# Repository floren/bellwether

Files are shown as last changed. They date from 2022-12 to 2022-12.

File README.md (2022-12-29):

# The Bellwether Mouse

This repo should contain everything you need to make a [Bellwether mouse](https://jfloren.net/bellwether.html).

Note that I've made several of these myself, but it's possible that I've forgotten a step or component somewhere.

I'm willing to answer questions to the best of my ability. I'll also consider assembling some portions of the mouse and mailing it out; send me an email if you want this.

The 3d models and the circuit are CC BY-NC-SA licensed. I believe this means that "group buys" (where 1 person coordinates ordering a bunch of PCBs and parts) are ok under this model.

## 3D-printed case

Inside the case/ subdirectory you'll find two FreeCAD files, "base" (the bottom part of the mouse) and "body" (the curved top which fits in your hand).

These should be printed in PLA. I've had good luck with my Prusa Mini. I strongly suggest using a raft when printing the body, and *not* using a raft for the base.

Check out the releases for pre-built STL files.

## PCB

The board was designed using KiCAD. If you use OSH Park, you should be able to just upload board/depraz_board.kicad_pcb directly on their site. For other PCB services, you may need to open KiCAD and export Gerber files etc.

## Circuit & BOM

You can check out the schematic in schematic.pdf

bom.csv is a circuit bill of materials. Most stuff should be available from parts companies in the US, but for the PMW3389 sensor you'll probably need to go to AliExpress (e.g. https://www.aliexpress.us/item/2251832705021246.html)

You'll also need 3 momentary pushbutton switches such as https://www.digikey.com/en/products/detail/5501M1BLKX/EG1701-ND/101654

Although you don't have to, I recommend using a DIP socket for the microcontroller in case you toast the microcontroller.

## Assembly

### Circuit assembly

In general it's all pretty straightforward but I strongly recommend installing the SMD level shifters first, all the rest of the components next, and then do the mouse sensor *last*.

### Doing the switches

I recommend gluing down the switches first. Gently pry off the button from each switch and set it aside. Then put a small dab of Gorilla Glue in the slot on the base, press the switch onto it, and make sure it's aligned straight. Use a clamp to hold the switch in place while the glue dries (I used something like https://www.amazon.com/Professional-Plastic-Backdrop-Photography-Improvement/dp/B08RXW32H4/). Once the glue is dry, make sure the switch is firmly seated and use an exacto knife to trim away any glue which oozed out, then press the button back onto the switch face.

Solder two wires onto each switch, on the normally-open pins. The wires should have Dupont pin connectors on the ends; I just took some jumper wires I had lying around (with a connector on each end) and cut them in half. See http://jfloren.net/content/bellwether/base2.jpg

### Physical assembly

You'll need the following parts to assemble the case:

* 8x M2x0.4mm heatserts: https://www.mcmaster.com/94459A120/
* 4x M2x0.4mm flathead screws (for the bottom): https://www.mcmaster.com/91294A003/
* 4x M2x0.4mm button head screws (to hold the board down): https://www.mcmaster.com/92095A451/

Additional stuff you'll want:

* A USB cable. Should be USB-A on one end, and a female pin header connector at the other. You can start with https://www.digikey.com/en/products/detail/assmann-wsw-components/A-USB20AM-OE-200BK28/10408422 and use https://www.amazon.com/Taiss-Ratcheting-Connector-Crimping-Terminal/dp/B0B11RLGDZ to crimp on a 4-pin header to the other end. You may be able to find these pre-made, e.g. https://www.amazon.com/dp/B07ZPT2NMT
* Friction tape (https://www.amazon.com/gp/product/B0000CBIAT) to wrap around the USB cable where it leaves the mouse. This appears to be what my original Depraz mouse used.
* Teflon tape to make skates for the bottom. I used https://www.amazon.com/gp/product/B01LZ44P6M and punched out pieces using https://www.amazon.com/gp/product/B00006IBK9

Use your soldering iron to install the heatserts flush in the corresponding holes of the case.

Position the lens on the bottom of the mouse sensor, then set the PCB on the 3d printed base. Use the button-head screws to hold down the PCB; don't overtighten!

Plug in the switches. Note that the headers on the board are labeled R, M, and L for right, middle, and left.

Plug the USB cable into the 4-pin USB header. Lay it across the board to where the cable hole in the case will go; mark this point and put a layer or two of friction tape on the cable there.

Gently slide the top of the case over the switches; there's a "right way" to do it, which takes a bit of gentle experimentation to find. Once you get the two pieces together, use flathead screws to hold them together.

Punch out four pieces of Teflon tape and stick them to the bottom for skates.

### Flashing the firmware

The firmware organization sucks, but I am not good enough at PIC programming to properly clean it up. PRs welcome.

Plug your PIC programmer into the PROGRAM header on the board.

Open MPLAB X IDE and load firmware/depraz/apps/usb/device/hid_mouse/firmware/low_pin_count_usb_development_kit_pic16f1459.x

I found that it worked when I set up the PICkit3 to provide power at 3.5V. Your other option is to plug in the USB cable before programming to power the device externally.

### Adding heft

You'll probably find that the mouse by itself is way too light. I hot-glued a bunch of lead fishing weights to the inside and it was much more pleasant.

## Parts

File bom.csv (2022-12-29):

Reference | Quantity | Value | Footprint | Datasheet
C1 | 1 | 0.1uF | Capacitor_THT:C_Disc_D8.0mm_W2.5mm_P5.00mm | ~
C2 | 1 | 4.7uF | Capacitor_THT:C_Disc_D4.7mm_W2.5mm_P5.00mm | ~
J1 | 1 | Switches | Connector_PinHeader_2.54mm:PinHeader_1x06_P2.54mm_Vertical | ~
J2 | 1 | PIC Programmer | Connector_PinHeader_2.54mm:PinHeader_1x05_P2.54mm_Vertical | ~
J3 | 1 | USB | Connector_PinHeader_2.54mm:PinHeader_1x04_P2.54mm_Vertical | ~
R1 R2 R3 | 3 | 1M | Resistor_THT:R_Axial_DIN0207_L6.3mm_D2.5mm_P5.08mm_Vertical | ~
R4 | 1 | 13 | Resistor_THT:R_Axial_DIN0207_L6.3mm_D2.5mm_P5.08mm_Vertical | ~
U1 | 1 | PIC16F1454-IP | Package_DIP:DIP-14_W7.62mm | http://ww1.microchip.com/downloads/en/DeviceDoc/41639A.pdf
U2 U3 | 2 | TXB0104D | Package_SO:SOIC-14_3.9x8.7mm_P1.27mm | http://www.ti.com/lit/ds/symlink/txb0104.pdf
U4 | 1 | S-817B20AY-B2-U | Package_TO_SOT_THT:TO-92L_Inline | https://www.ablic.com/en/doc/datasheet/voltage_regulator/S817_E.pdf
U5 | 1 | PMW3389DM | depraz_board:pmw3389

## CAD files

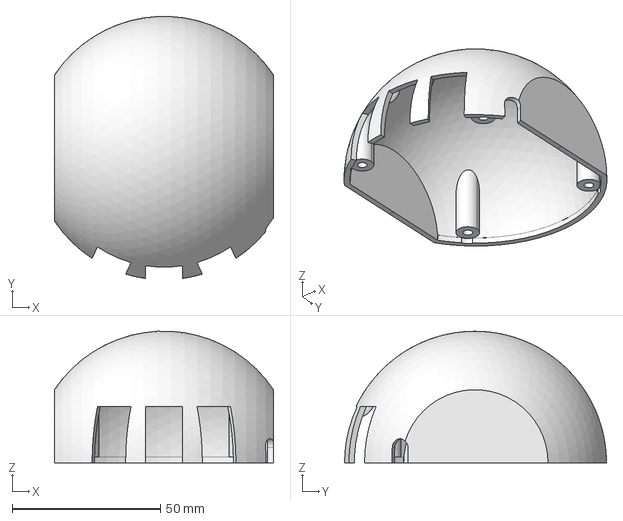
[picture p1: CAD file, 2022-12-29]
case/body.FCStd
74.1 x 88.5 x 44.4 mm

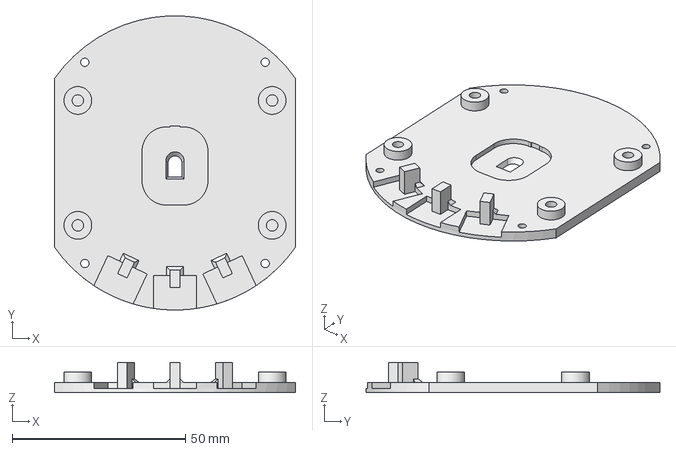
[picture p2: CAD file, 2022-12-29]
case/base.FCStd
69.5 x 84.7 x 8.75 mm

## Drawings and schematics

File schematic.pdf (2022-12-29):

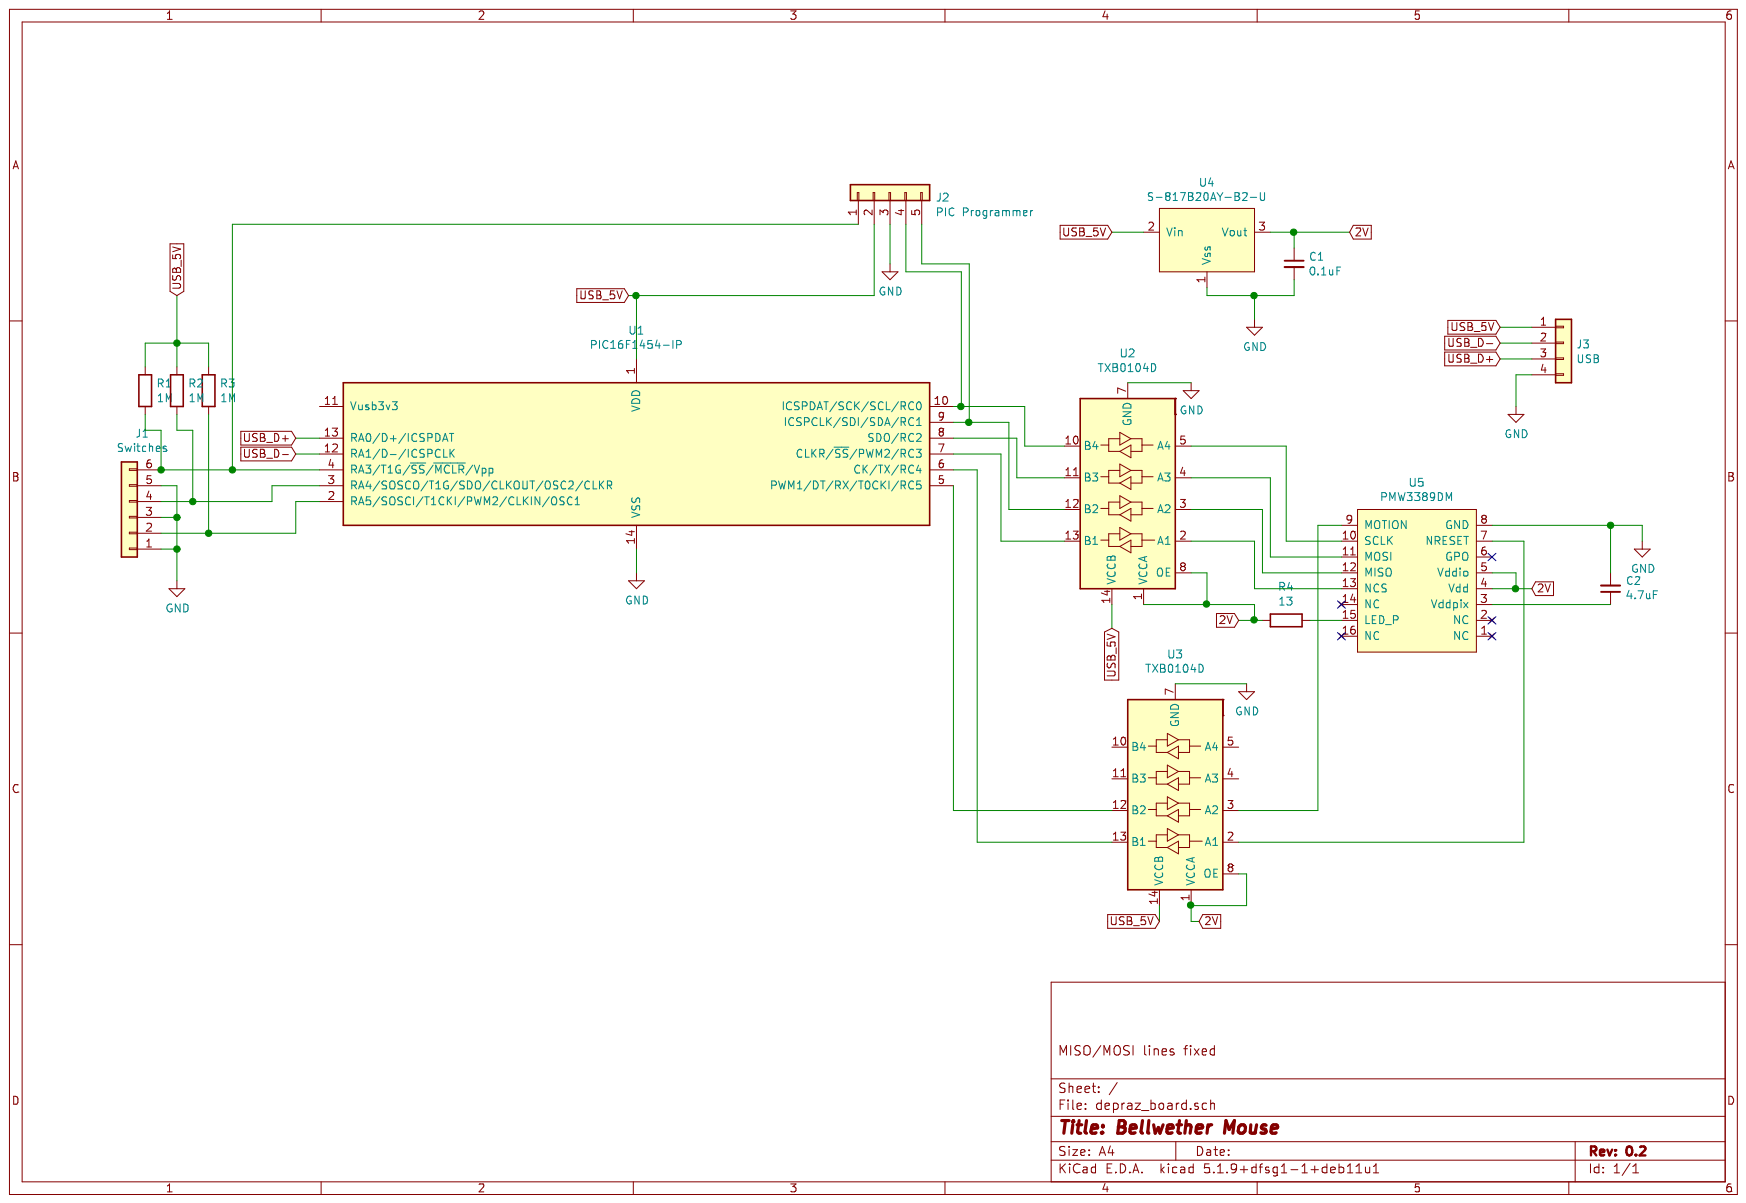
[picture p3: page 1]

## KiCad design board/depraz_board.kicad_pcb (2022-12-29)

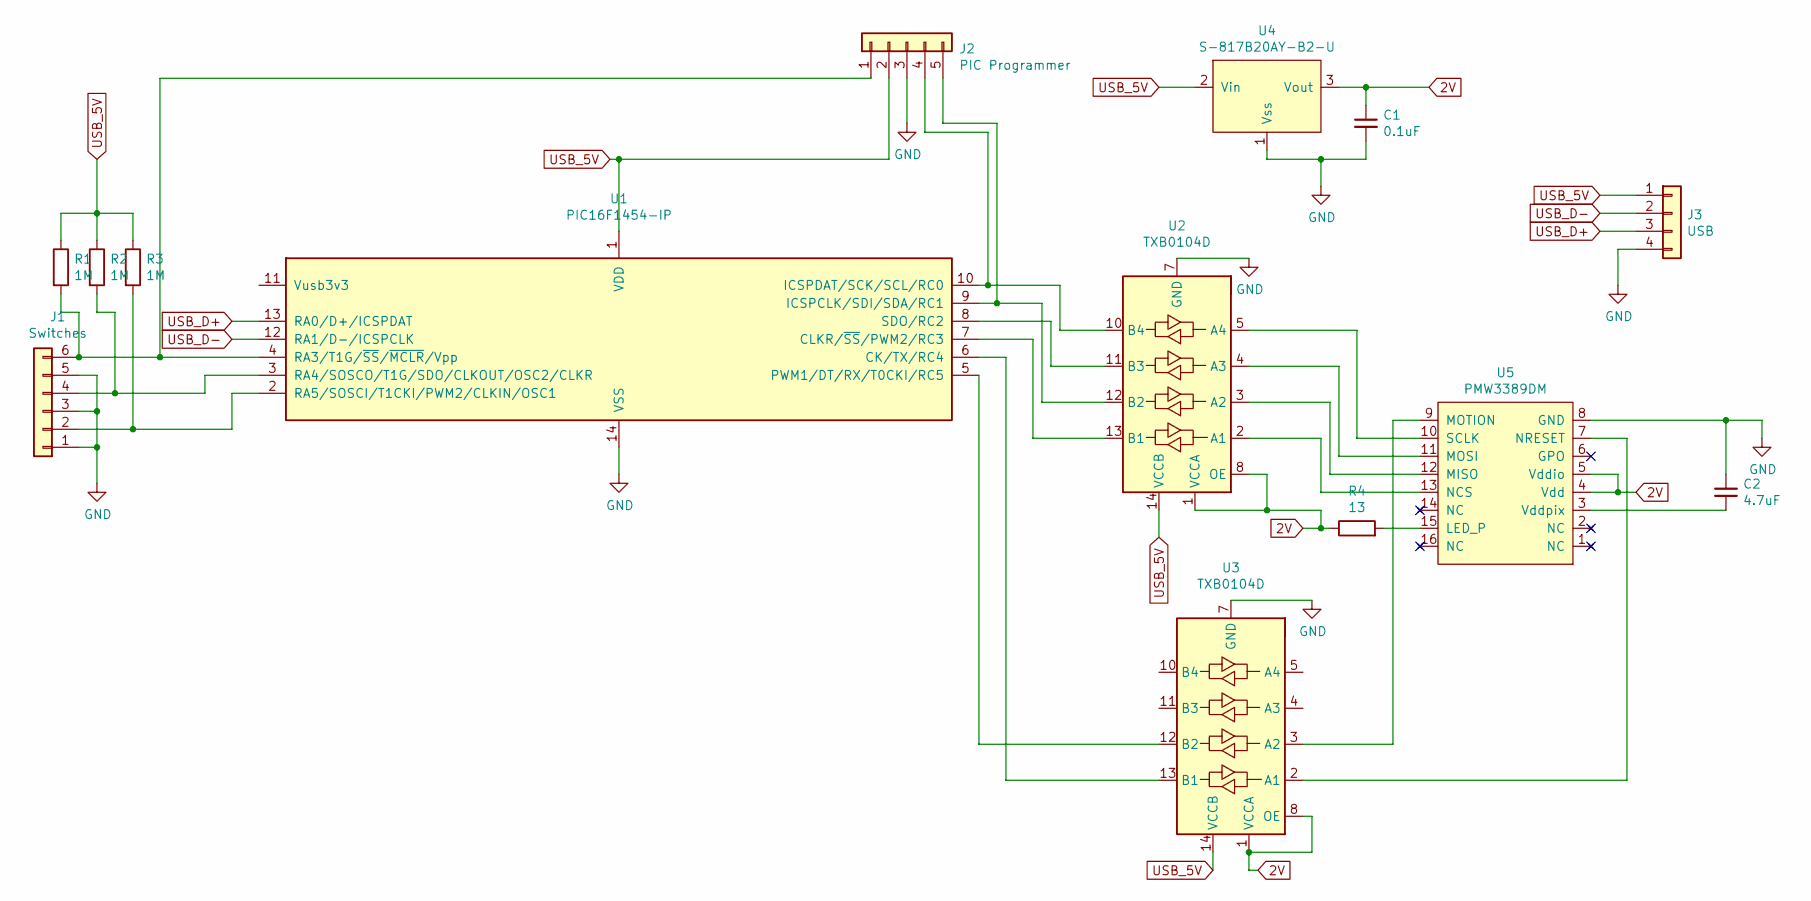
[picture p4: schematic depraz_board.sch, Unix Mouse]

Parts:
C1: 0.1uF; C_Disc_D8.0mm_W2.5mm_P5.00mm
C2: 4.7uF; C_Disc_D4.7mm_W2.5mm_P5.00mm
J1: Switches; PinHeader_1x06_P2.54mm_Vertical
J2: PIC Programmer; PinHeader_1x05_P2.54mm_Vertical
J3: USB; PinHeader_1x04_P2.54mm_Vertical
R1, R2, R3: 1M; R_Axial_DIN0207_L6.3mm_D2.5mm_P5.08mm_Vertical
R4: 13; R_Axial_DIN0207_L6.3mm_D2.5mm_P5.08mm_Vertical
U1: PIC16F1454-IP; DIP-14_W7.62mm
U2, U3: TXB0104D; SOIC-14_3.9x8.7mm_P1.27mm
U4: S-817B20AY-B2-U; TO-92L_Inline
U5: PMW3389DM; pmw3389

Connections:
2V: C1.1, R4.1, U2.1 (VCCA), U2.8 (OE), U3.1 (VCCA), U3.8 (OE), U4.3 (Vout), U5.4 (Vdd), U5.5 (Vddio)
GND: C1.2, C2.2, J1.1, J1.3, J1.5, J2.3, J3.4, U1.14 (VSS), U2.7 (GND), U3.7 (GND), U4.1 (Vss), U5.8 (GND)
unnamed: C2.1, U5.3 (Vddpix)
unnamed: J1.2, R3.2, U1.2 (RA5/SOSCI/T1CKI/PWM2/CLKIN/OSC1)
unnamed: J1.4, R2.2, U1.3 (RA4/SOSCO/T1G/SDO/CLKOUT/OSC2/CLKR)
unnamed: J1.6, J2.1, R1.2, U1.4 (RA3/T1G/~SS~/~MCLR~/Vpp)
unnamed: J2.4, U1.10 (ICSPDAT/SCK/SCL/RC0), U2.10 (B4)
unnamed: J2.5, U1.9 (ICSPCLK/SDI/SDA/RC1), U2.12 (B2)
unnamed: R4.2, U5.15 (LED_P)
unnamed: U1.5 (PWM1/DT/RX/T0CKI/RC5), U3.12 (B2)
unnamed: U1.6 (CK/TX/RC4), U3.13 (B1)
unnamed: U1.7 (CLKR/~SS~/PWM2/RC3), U2.13 (B1)
unnamed: U1.8 (SDO/RC2), U2.11 (B3)
unnamed: U2.2 (A1), U5.13 (NCS)
unnamed: U2.3 (A2), U5.12 (MISO)
unnamed: U2.4 (A3), U5.11 (MOSI)
unnamed: U2.5 (A4), U5.10 (SCLK)
unnamed: U3.2 (A1), U5.7 (NRESET)
unnamed: U3.3 (A2), U5.9 (MOTION)
USB_5V: J2.2, J3.1, R1.1, R2.1, R3.1, U1.1 (VDD), U2.14 (VCCB), U3.14 (VCCB), U4.2 (Vin)
USB_D+: J3.3, U1.13 (RA0/D+/ICSPDAT)
USB_D-: J3.2, U1.12 (RA1/D-/ICSPCLK)

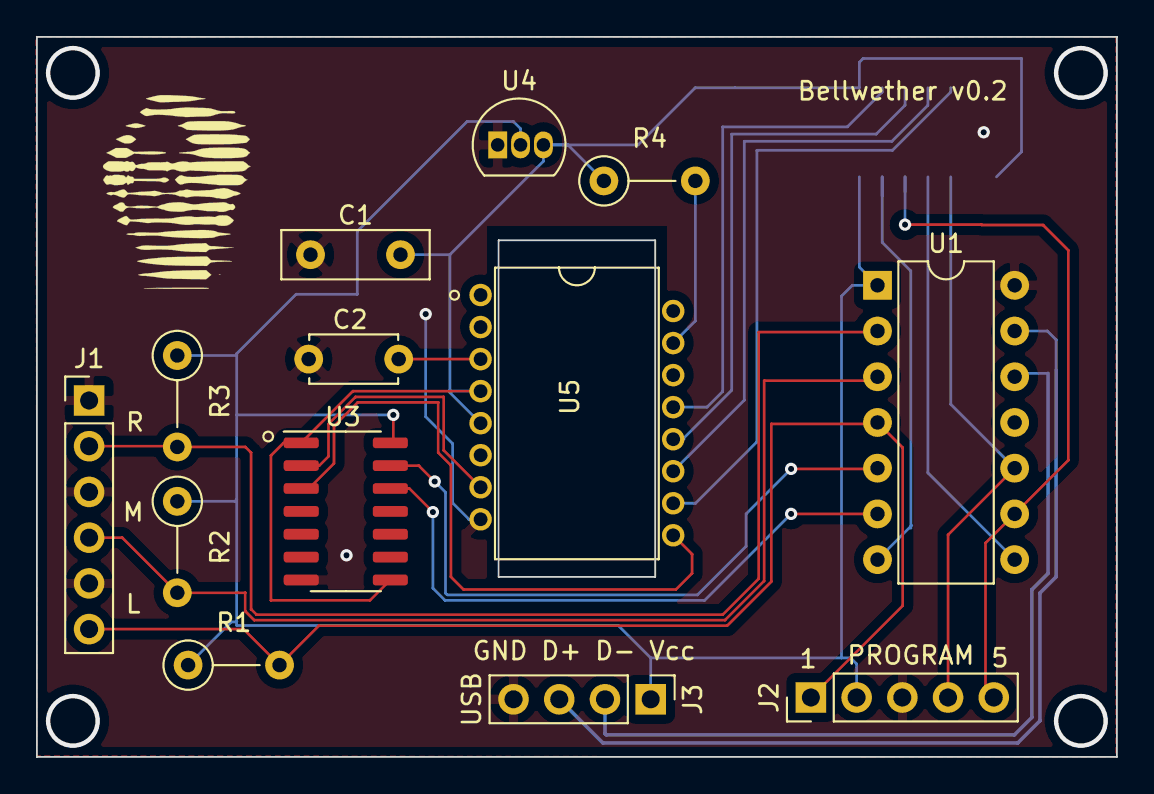
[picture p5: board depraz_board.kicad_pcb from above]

Board: 2 copper layers, 60.0 x 40.0 mm, 14 parts (1 on the bottom side), 22 nets.

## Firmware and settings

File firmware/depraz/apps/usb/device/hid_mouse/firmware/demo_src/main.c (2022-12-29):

/*******************************************************************************
Copyright 2016 Microchip Technology Inc. (www.microchip.com)

Licensed under the Apache License, Version 2.0 (the "License");
you may not use this file except in compliance with the License.
You may obtain a copy of the License at

    http://www.apache.org/licenses/LICENSE-2.0

Unless required by applicable law or agreed to in writing, software
distributed under the License is distributed on an "AS IS" BASIS,
WITHOUT WARRANTIES OR CONDITIONS OF ANY KIND, either express or implied.
See the License for the specific language governing permissions and
limitations under the License.

To request to license the code under the MLA license (www.microchip.com/mla_license), 
please contact mla_licensing@microchip.com
*******************************************************************************/

/** INCLUDES *******************************************************/
#include "system.h"

#include "usb_device.h"
#include "usb_device_hid.h"
#include "usb_device_cdc.h"

#include "app_device_mouse.h"
#include "app_led_usb_status.h"
#include "pmw3389.h"


void spi_begin() {
    NCS = 0;
}

void spi_end() {
    NCS = 1;
}

unsigned char spi_read_reg(unsigned char addr) {
    unsigned char data;
    unsigned char x;
    
    x = SSPBUF;
    // Send the address we want to read
    spi_begin();
    // write the address with MSB low (read)
    SSPBUF = addr & 0x7f;
    while (!BF);
    x = SSPBUF; // read whatever they sent, it doesn't matter
    __delay_us(35); // tsrad
    
    // Now get the result they sent
    SSPBUF = 0x1; // send some nonsense, so we can receive the actual value
    while (!BF);
    spi_end();
    __delay_us(20);
    data = SSPBUF; // read the data

    return data;
}

void spi_write_reg(unsigned char addr, unsigned char value) {
    unsigned char x;
    spi_begin();
    // write the address with MSB high
    SSPBUF = addr | 0x80;
    while (BF == 0);
    x = SSPBUF; // read whatever nonsense they sent
    __delay_us(1);
    // Now send the data
    SSPBUF = value;
    while (BF == 0);
    x = SSPBUF; // read whatever we received, we don't care
    __delay_us(20);
    spi_end();
    __delay_us(100);
}

void get_burst(unsigned char* buff) {
    int i;
    
    spi_begin();
    // write somethign to motion burst buffer
    spi_write_reg(Motion_Burst, 0x1);
    
    // Read from the motion burst buffer
    spi_read_reg(Motion_Burst);
    __delay_us(35);
    
    // Now read 12 bytes
    for (i = 0; i < 12; i++) {
        SSPBUF = Motion_Burst;
        while (BF == 0);
        buff[i] = SSPBUF;
    }
    spi_end();
}

/********************************************************************
 * Function:        void main(void)
 *
 * PreCondition:    None
 *
 * Input:           None
 *
 * Output:          None
 *
 * Side Effects:    None
 *
 * Overview:        Main program entry point.
 *
 * Note:            None
 *******************************************************************/
MAIN_RETURN main(void)
{
    SYSTEM_Initialize(SYSTEM_STATE_USB_START);

    USBDeviceInit();
    USBDeviceAttach();

    ANSELA = 0x0;
    ANSELC = 0x0;
    TRISA=0b00111000;
    TRISC=0b00100010;
    
    // Reset SPI on the PIC
    SSPCON1 = 0;
    SSPCON2 = 0;
    SSPCON1bits.SSPM = 0x1;
    SSPCON1bits.CKP = 1; // clock polarity
    SSPSTATbits.CKE = 0; // clock edge select
    SSPCON1bits.SSPEN = 1; // enable SPI

    __delay_ms(1);
    
    // reset device's SPI port
    spi_begin();
    __delay_us(50);
    spi_end();
    __delay_us(50);

    
    // Reset the sensor
    NRESET = 0;
    __delay_ms(50);
    NRESET = 1;
    __delay_ms(50);
    
    unsigned char x;
    x = spi_read_reg(Product_ID);
    x = spi_read_reg(Product_ID);
    x = spi_read_reg(Motion);
    x = spi_read_reg(Delta_X_L);
    x = spi_read_reg(Delta_X_H);
    x = spi_read_reg(Delta_Y_L);
    x = spi_read_reg(Delta_Y_H);
    __delay_ms(1);
    
    // Set the CPI
#define CPI 800
    uint16_t cpival;
    cpival = CPI / 50;
    spi_write_reg(Resolution_L, (cpival & 0xFF));
    spi_write_reg(Resolution_H, (cpival >> 8) & 0xFF);
    
    //write_firmware();
    
    // write to Motion register to kick things off
    spi_write_reg(Motion, 0x1);
    
    int8_t motion, xl, xh, yl, yh;
    int16_t X, Y;
    int8_t left, right, mid;
    while(1)
    {
        //spi_read_reg(Product_ID);
        motion = 0x00;
        motion = spi_read_reg(Motion);
        dx = dy = 0;
        if (motion & 0x80) {
            xl = spi_read_reg(Delta_X_L);
            xh = spi_read_reg(Delta_X_H);
            yl = spi_read_reg(Delta_Y_L);
            yh = spi_read_reg(Delta_Y_H);
            X = (xh << 8) | xl;
            Y = (yh << 8) | yl;
            dx = -X;
            dy = -Y;
        }
        
        // Watchdog... if we actually read from the register,
        // this bit will be set
        if (motion & 0x20) {
            CLRWDT();
        }
        
        // Mouse button debouncing
        left = BUTTON_LEFT;
        if (!left) {
            // button is currently pressed
            leftCounter = (leftCounter<=THRESH)?leftCounter+1:leftCounter;
        } else {
            leftCounter = (leftCounter>0)?leftCounter-1:0;
        }
        
        right = BUTTON_RIGHT;
        if (!right) {
            // button is currently pressed
            rightCounter = (rightCounter<=THRESH)?rightCounter+1:rightCounter;
        } else {
            rightCounter = (rightCounter>0)?rightCounter-1:0;
        }
        
        mid = BUTTON_MID;
        if (!mid) {
            // button is currently pressed
            midCounter = (midCounter<=THRESH)?midCounter+1:midCounter;
        } else {
            midCounter = (midCounter>0)?midCounter-1:0;
        }
     
        SYSTEM_Tasks();

        #if defined(USB_POLLING)
            // Interrupt or polling method.  If using polling, must call
            // this function periodically.  This function will take care
            // of processing and responding to SETUP transactions
            // (such as during the enumeration process when you first
            // plug in).  USB hosts require that USB devices should accept
            // and process SETUP packets in a timely fashion.  Therefore,
            // when using polling, this function should be called
            // regularly (such as once every 1.8ms or faster** [see
            // inline code comments in usb_device.c for explanation when
            // "or faster" applies])  In most cases, the USBDeviceTasks()
            // function does not take very long to execute (ex: <100
            // instruction cycles) before it returns.
            USBDeviceTasks();
        #endif
  
        //Application specific tasks
        APP_DeviceMouseTasks();
        
        //CDCTxService();

        __delay_ms(2);
    }//end while
}//end main


/*******************************************************************************
 End of File
*/

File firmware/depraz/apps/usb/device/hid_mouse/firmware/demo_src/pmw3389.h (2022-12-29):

/* Microchip Technology Inc. and its subsidiaries.  You may use this software 
 * and any derivatives exclusively with Microchip products. 
 * 
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
 * IN NO EVENT WILL MICROCHIP BE LIABLE FOR ANY INDIRECT, SPECIAL, PUNITIVE, 
 * INCIDENTAL OR CONSEQUENTIAL LOSS, DAMAGE, COST OR EXPENSE OF ANY KIND 
 * WHATSOEVER RELATED TO THE SOFTWARE, HOWEVER CAUSED, EVEN IF MICROCHIP HAS 
 * BEEN ADVISED OF THE POSSIBILITY OR THE DAMAGES ARE FORESEEABLE.  TO THE 
 * FULLEST EXTENT ALLOWED BY LAW, MICROCHIP'S TOTAL LIABILITY ON ALL CLAIMS 
 * IN ANY WAY RELATED TO THIS SOFTWARE WILL NOT EXCEED THE AMOUNT OF FEES, IF 
 * ANY, THAT YOU HAVE PAID DIRECTLY TO MICROCHIP FOR THIS SOFTWARE.
 *
 * MICROCHIP PROVIDES THIS SOFTWARE CONDITIONALLY UPON YOUR ACCEPTANCE OF THESE 
 * TERMS. 
 */

/* 
 * File:   
 * Author: 
 * Comments:
 * Revision history: 
 */

// This is a guard condition so that contents of this file are not included
// more than once.  
#ifndef PMW3389
#define	PMW3389

#include <xc.h> // include processor files - each processor file is guarded.  

// Pins on the PMW chip
#define NRESET RC4
#define NCS RC3
#define MOSI RC2
#define MISO RC1
#define SCK RC0

#define BUTTON_LEFT RA3
#define BUTTON_RIGHT RA5
#define BUTTON_MID RA4

#define Product_ID  0x00
#define Revision_ID 0x01
#define Motion  0x02
#define Delta_X_L 0x03
#define Delta_X_H 0x04
#define Delta_Y_L 0x05
#define Delta_Y_H 0x06
#define SQUAL 0x07
#define Raw_Data_Sum  0x08
#define Maximum_Raw_data  0x09
#define Minimum_Raw_data  0x0A
#define Shutter_Lower 0x0B
#define Shutter_Upper 0x0C
#define Control 0x0D
#define Resolution_L 0x0E
#define Resolution_H 0x0F
#define Config2 0x10
#define Angle_Tune  0x11
#define Frame_Capture 0x12
#define SROM_Enable 0x13
#define Run_Downshift 0x14
#define Rest1_Rate_Lower  0x15
#define Rest1_Rate_Upper  0x16
#define Rest1_Downshift 0x17
#define Rest2_Rate_Lower  0x18
#define Rest2_Rate_Upper  0x19
#define Rest2_Downshift 0x1A
#define Rest3_Rate_Lower  0x1B
#define Rest3_Rate_Upper  0x1C
#define Observation 0x24
#define Data_Out_Lower  0x25
#define Data_Out_Upper  0x26
#define Raw_Data_Dump 0x29
#define SROM_ID 0x2A
#define Min_SQ_Run  0x2B
#define Raw_Data_Threshold  0x2C
#define Config5 0x2F
#define Power_Up_Reset  0x3A
#define Shutdown  0x3B
#define Inverse_Product_ID  0x3F
#define LiftCutoff_Tune3  0x41
#define Angle_Snap  0x42
#define LiftCutoff_Tune1  0x4A
#define Motion_Burst  0x50
#define LiftCutoff_Tune_Timeout 0x58
#define LiftCutoff_Tune_Min_Length  0x5A
#define SROM_Load_Burst 0x62
#define Lift_Config 0x63
#define Raw_Data_Burst  0x64
#define LiftCutoff_Tune2  0x65

#endif	/* XC_HEADER_TEMPLATE_H */
